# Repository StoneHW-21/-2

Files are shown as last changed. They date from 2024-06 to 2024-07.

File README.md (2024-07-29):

# Voice Assistant Camera Wearable

Improved my previous [ESP32-CAM Semantic Search Wearable](https://github.com/xanderchinxyz/ESP32-CAM-Semantic-Search) by improving the physical design and adding a voice assistant powered by:
- [A local multimodal large language model](https://www.ollama.com/library/moondream)
- [Groq](https://groq.com/) with Retrieval Augmented Generation (RAG)
- [VOSK speech recognition model](https://alphacephei.com/vosk/).

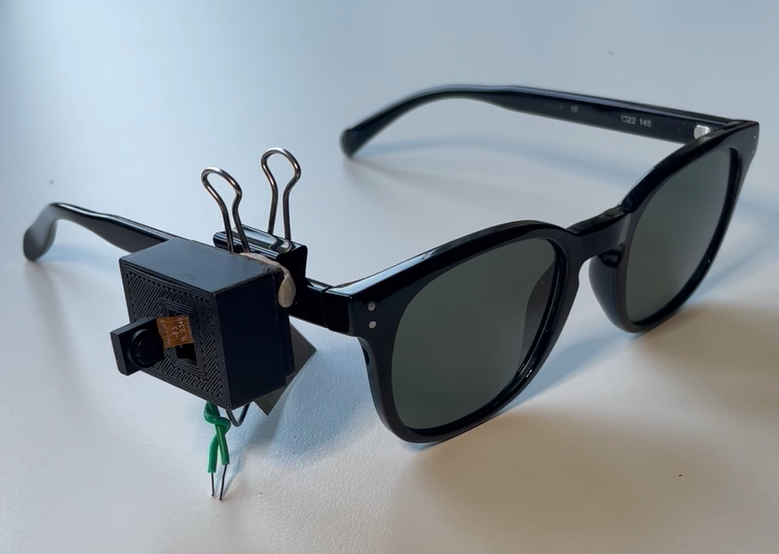
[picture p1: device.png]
Device


## Video Demo

[](https://youtube.com/shorts/sPIqjVPMnrE)

https://youtube.com/shorts/sPIqjVPMnrE

## How It Works
When the wearable is switched on and the user is connected to the software, the wearable will start taking pictures every 5 seconds which will be sent over via Bluetooth Low Energy (BLE). Once the picture is received it is sent to a multimodal local language model running on Ollama which generates a description of the image. The image is saved to the [Pictures](https://github.com/xanderchinxyz/Voice-Assistant-Camera-Wearable/tree/main/Pictures) folder and the file name and description are added to a vector database and data frame containing past image files and descriptions. If the user presses the wire to ask the wearable a question, the wearable will turn off the camera and start recording audio packets. These audio packets are sent via BLE and processed by VOSK to generate the user transcription query. This transcription query is vectorized to obtain relevant context from the vector database and the question and context are sent to Groq for a super-fast response with an appropriate answer. Once the response is received, a [Text-To-Speech model](https://pypi.org/project/pyttsx3/) reads out the response, and the top 5 most relevant images are displayed on the screen. The user can then ask follow-up questions or press the wire to resume capturing images. When the user closes the software, the image file names and descriptions are saved to `image-descriptions.csv`.

## Setup and Installation
### Hardware and Components
- 1 XIAO ESP32 S3 Sense board
- 1 [220 mAh LiPo battery](https://www.amazon.ca/dp/B0CKRBTW8Z?psc=1&ref=ppx_yo2ov_dt_b_product_details)
- 1 3-way switch
- 1 [3D Printed Case + Lid](https://github.com/xanderchinxyz/Voice-Assistant-Camera-Wearable/tree/main/STL-Files)
- 2 Wires
- 1 Binder clip attached to the case with some sticky tack for clipping onto a pair of glasses

Solder components like so:
1. One wire connects to D0
2. The other wire connects to GND or BAT- and interlock this wire with the other wire (it helps with registering touch presses)
3. Solder the leftmost prong of the 3-way switch to the BAT+ pin
4. Solder the negative battery wire to the BAT- pin and the positive battery wire to the middle prong of the 3-way switch



### Software
1. Clone the repo with `git clone https://github.com/xanderchinxyz/Voice-Assistant-Camera-Wearable.git`
2. In the root folder install required libraries and dependencies with `pip install -r requirements.txt`
3. Create a `.env` in the root directory and add your Groq API key by pasting `GROQ_API_KEY="YOUR_API_KEY_HERE"` in the file
4. Install Ollama and download the [moondream2 model](https://www.ollama.com/library/moondream) by running `ollama pull moondream` in a terminal
5. Install the firmware onto the XIAO ESP32 S3 board:
   1. Go to the [firmware folder](https://github.com/xanderchinxyz/Voice-Assistant-Camera-Wearable/tree/main/xiao-firmware) and open the `.ino` file in the Arduino IDE
   2. Follow the software preparation steps to set up the Arduino IDE for the XIAO ESP32S3 board:
      - Add ESP32 board package to your Arduino IDE:
        - Navigate to File > Preferences, and fill "Additional Boards Manager URLs" with the URL: `https://raw.githubusercontent.com/espressif/arduino-esp32/gh-pages/package_esp32_index.json`
        - Navigate to Tools > Board > Boards Manager..., type the keyword `esp32` in the search box, select the latest version of `esp32`, and install it.
      - Select your board and port:
        - On top of the Arduino IDE, select the port (likely to be COM3 or higher).
        - Search for `xiao` in the development board on the left and select `XIAO_ESP32S3`.
   
   3. Before you flash go to the "Tools" drop-down in the Arduino IDE and make sure you set "PSRAM:" to "PSRAM: "OPI PSRAM"
      
      Like this
   4. Upload the firmware to the XIAO ESP32S3 board by putting it in BOOT mode (press the boot button down, then click the reset button, then release the boot button)
6. Run `main.py`
   - Make sure the Ollama server is on by running `ollama serve` in a terminal
   - When first running the script it will probably take a while to download the VOSK model
   - To connect to the device, click on the window popup, press the "Select BLE Device" button, and wait for the device to show up (don't mind the UI 😅)

## Acknowledgements
Thank you to [OpenGlass](https://github.com/BasedHardware/OpenGlass) for open-sourcing their code which helped me create the embedded software for the XIAO ESP32 S3.

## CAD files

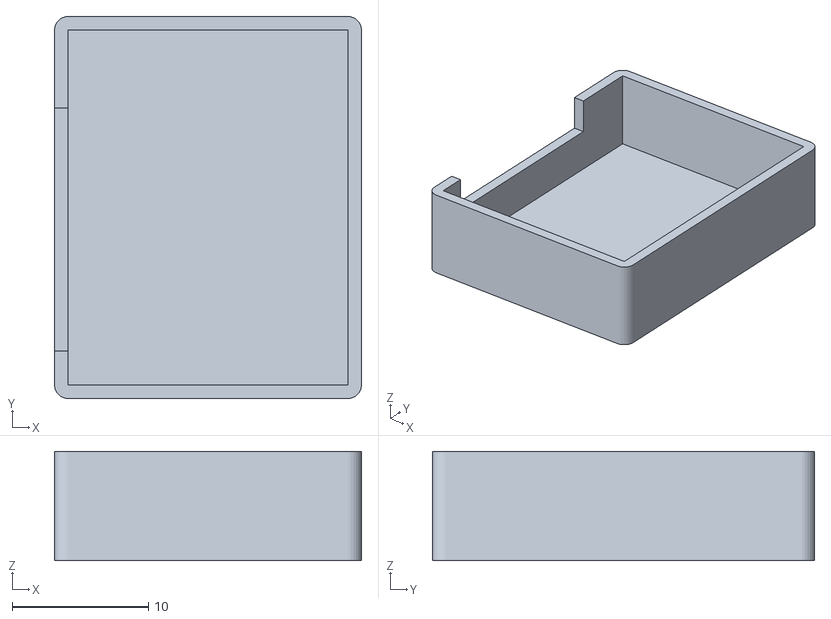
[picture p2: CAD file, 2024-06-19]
STL-Files/220 mAh bottom.stl
22.5 x 28.0 x 8.00

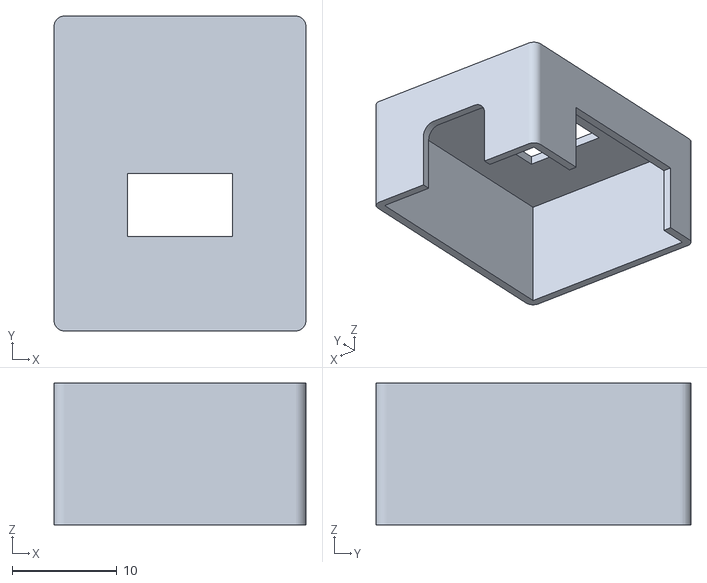
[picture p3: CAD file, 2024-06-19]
STL-Files/220 mAh lid.stl
24.0 x 30.0 x 13.5

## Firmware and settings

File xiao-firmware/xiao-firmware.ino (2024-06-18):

#define CAMERA_MODEL_XIAO_ESP32S3
#include <I2S.h>
#include <BLE2902.h>
#include <BLEDevice.h>
#include <BLEUtils.h>
#include <BLEScan.h>
#include <BLEAdvertisedDevice.h>
#include "esp_camera.h"
#include "camera_pins.h"
#include "mulaw.h"

//
// BLE
//

static BLEUUID serviceUUID("19B10000-E8F2-537E-4F6C-D104768A1214");
static BLEUUID audioCharUUID("19B10001-E8F2-537E-4F6C-D104768A1214");
static BLEUUID audioCodecUUID("19B10002-E8F2-537E-4F6C-D104768A1214");
static BLEUUID photoCharUUID("19B10005-E8F2-537E-4F6C-D104768A1214");
static BLEUUID commandUUID("19B10006-E8F2-537E-4F6C-D104768A1214");

BLECharacteristic *audio;
BLECharacteristic *photo;
BLECharacteristic *command;
bool connected = false;

class ServerHandler: public BLEServerCallbacks
{
  void onConnect(BLEServer *server)
  {
    connected = true;
    Serial.println("Connected");
  }

  void onDisconnect(BLEServer *server)
  {
    connected = false;
    Serial.println("Disconnected");
    BLEDevice::startAdvertising();
  }
};

void configure_ble() {
  BLEDevice::init("OpenGlass");
  BLEServer *server = BLEDevice::createServer();
  BLEService *service = server->createService(serviceUUID);

  // Audio service
  audio = service->createCharacteristic(
    audioCharUUID,
    BLECharacteristic::PROPERTY_READ | BLECharacteristic::PROPERTY_NOTIFY
  );
  BLE2902 *ccc = new BLE2902();
  ccc->setNotifications(true);
  audio->addDescriptor(ccc);

  // Photo service
  photo = service->createCharacteristic(
    photoCharUUID,
    BLECharacteristic::PROPERTY_READ | BLECharacteristic::PROPERTY_NOTIFY
  );
  ccc = new BLE2902();
  ccc->setNotifications(true);
  photo->addDescriptor(ccc);

  // Codec service
  BLECharacteristic *codec = service->createCharacteristic(
    audioCodecUUID,
    BLECharacteristic::PROPERTY_READ
  );
  uint8_t codecId = 11; // MuLaw 8mhz
  codec->setValue(&codecId, 1);

  //TTS service
  command = service->createCharacteristic(
    commandUUID,
    BLECharacteristic::PROPERTY_READ | BLECharacteristic::PROPERTY_NOTIFY
  );
  ccc = new BLE2902();
  ccc->setNotifications(true);
  command->addDescriptor(ccc);

  // Service
  server->setCallbacks(new ServerHandler());
  service->start();

  BLEAdvertising *advertising = BLEDevice::getAdvertising();
  advertising->addServiceUUID(service->getUUID());
  advertising->setScanResponse(true);
  advertising->setMinPreferred(0x0);
  advertising->setMinPreferred(0x1F);
  BLEDevice::startAdvertising();
}

camera_fb_t *fb;

bool take_photo() {

  // Release buffer
  if (fb) {
    Serial.println("Release FB");
    esp_camera_fb_return(fb);
  }

  // Take a photo
  Serial.println("Taking photo...");
  fb = esp_camera_fb_get();
  if (!fb) {
    Serial.println("Failed to get camera frame buffer");
    return false;
  }

  return true;
}

//
// Microphone
//

#define VOLUME_GAIN 3

static size_t recording_buffer_size = 200;
static size_t compressed_buffer_size = 493 + 2; /* header */
static uint8_t *s_recording_buffer = nullptr;
static uint8_t *s_compressed_frame = nullptr;
static uint8_t *s_compressed_frame_2 = nullptr;

void configure_microphone() {

  // start I2S at 16 kHz with 16-bits per sample
  I2S.setAllPins(-1, 42, 41, -1, -1);
  if (!I2S.begin(PDM_MONO_MODE, 16000, 16)) {
    Serial.println("Failed to initialize I2S!");
    while (1); // do nothing
  }

  // Allocate buffers
  s_recording_buffer = (uint8_t *) ps_calloc(recording_buffer_size, sizeof(uint8_t));
  s_compressed_frame = (uint8_t *) ps_calloc(compressed_buffer_size, sizeof(uint8_t));
  s_compressed_frame_2 = (uint8_t *) ps_calloc(compressed_buffer_size, sizeof(uint8_t));
}

size_t read_microphone() {
  size_t bytes_recorded = 0;
  esp_i2s::i2s_read(esp_i2s::I2S_NUM_0, s_recording_buffer, recording_buffer_size, &bytes_recorded, portMAX_DELAY);
  return bytes_recorded;
}

//
// Camera
//

void configure_camera() {
  camera_config_t config;
  config.ledc_channel = LEDC_CHANNEL_0;
  config.ledc_timer = LEDC_TIMER_0;
  config.pin_d0 = Y2_GPIO_NUM;
  config.pin_d1 = Y3_GPIO_NUM;
  config.pin_d2 = Y4_GPIO_NUM;
  config.pin_d3 = Y5_GPIO_NUM;
  config.pin_d4 = Y6_GPIO_NUM;
  config.pin_d5 = Y7_GPIO_NUM;
  config.pin_d6 = Y8_GPIO_NUM;
  config.pin_d7 = Y9_GPIO_NUM;
  config.pin_xclk = XCLK_GPIO_NUM;
  config.pin_pclk = PCLK_GPIO_NUM;
  config.pin_vsync = VSYNC_GPIO_NUM;
  config.pin_href = HREF_GPIO_NUM;
  config.pin_sscb_sda = SIOD_GPIO_NUM;
  config.pin_sscb_scl = SIOC_GPIO_NUM;
  config.pin_pwdn = PWDN_GPIO_NUM;
  config.pin_reset = RESET_GPIO_NUM;
  config.xclk_freq_hz = 20000000;
  config.frame_size = FRAMESIZE_UXGA;
  config.pixel_format = PIXFORMAT_JPEG; // for streaming
  config.fb_count = 1;

  config.jpeg_quality = 10;
  config.frame_size = FRAMESIZE_QVGA;
  config.grab_mode = CAMERA_GRAB_LATEST;
  config.fb_location = CAMERA_FB_IN_PSRAM;

  // camera init
  esp_err_t err = esp_camera_init(&config);
  if (err != ESP_OK) {
    Serial.printf("Camera init failed with error 0x%x", err);
    return;
  }
}

//
// Main
//


void setup() {
  Serial.begin(921600);
  Serial.println("Setup");
  Serial.println("Starting BLE...");
  configure_ble();
  Serial.println("Starting Microphone...");
  configure_microphone();
  Serial.println("Starting Camera...");
  configure_camera();
  Serial.println("OK");
}

uint16_t frame_count = 0;
unsigned long lastCaptureTime = 0;
size_t sent_photo_bytes = 0;
size_t sent_photo_frames = 0;
bool need_send_photo = false;

bool toggled = false;
bool touching = false;

void loop() {
  //handle touch buttons:
  uint32_t touch0 = touchRead(D0);
  if((touch0 > 30000) && !touching) {
    touching = true;
    toggled = !toggled;
    uint8_t data = toggled ? 255 : 0;
    command->setValue(&data, 1);
    command->notify();
    Serial.println(data);
  } else if(touch0 <= 30000) {
    touching = false;
  }

  // Read from mic
  size_t bytes_recorded = read_microphone();

  // Push to BLE
  if (bytes_recorded > 0 && connected && toggled) {

    for (size_t i = 0; i < bytes_recorded; i += 2) {
      (*(uint16_t *)(s_recording_buffer+i)) <<= VOLUME_GAIN;
    }
    audio->setValue(s_recording_buffer, bytes_recorded);
    audio->notify();
    frame_count++;
  }

  // Take a photo
  unsigned long now = millis();
  if ((now - lastCaptureTime) >= 5000 && !need_send_photo && connected && !toggled) {
    if (take_photo()) {
      need_send_photo = true;
      sent_photo_bytes = 0;
      sent_photo_frames = 0;
      lastCaptureTime = now;
    }
  }

  // Push to BLE
  if (need_send_photo && !toggled) {
    size_t remaining = fb->len - sent_photo_bytes;
    Serial.println("packet: " + String(sent_photo_frames));
    if (remaining > 0) {
      // Populate buffer
      s_compressed_frame_2[0] = sent_photo_frames & 0xFF;         //
      s_compressed_frame_2[1] = (sent_photo_frames >> 8) & 0xFF;  //packet number
      size_t bytes_to_copy = remaining;
      if (bytes_to_copy > 493) {  
        bytes_to_copy = 493;
      }
      memcpy(&s_compressed_frame_2[2], &fb->buf[sent_photo_bytes], bytes_to_copy);  //all the rest of the photo data
      
      // Push to BLE
      photo->setValue(s_compressed_frame_2, bytes_to_copy + 2);
      photo->notify();
      sent_photo_bytes += bytes_to_copy;
      sent_photo_frames++;
    } else {

      // End flag
      s_compressed_frame_2[0] = 0xFF;
      s_compressed_frame_2[1] = 0xFF;
      photo->setValue(s_compressed_frame_2, 2);
      photo->notify();

      Serial.println("Photo sent");
      need_send_photo = false;
    }
  }

  // Delay to ensure proper transmission of bluetooth packets
  delay(4);
}

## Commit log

2024-06-19 added stl files
    [220 mAh bottom.stl, 220 mAh lid.stl]
2024-06-19 added soldered components image
2024-06-19 uploaded device picture
